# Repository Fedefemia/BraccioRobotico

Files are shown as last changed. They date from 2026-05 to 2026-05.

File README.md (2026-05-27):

# Braccio Robotico 3 DOF - Sistema di Controllo Distribuito MQTT

## Autori: Femia Federico, Storato Nicola
Classe: 5cii
Anno Scolastico: 2025/2026
Panoramica dell'Architettura

Il progetto consiste nell'implementazione hardware e firmware di un braccio robotico a 3 gradi di libertà (DOF). L'architettura prevede un sistema di attuazione e controllo remoto basato sul protocollo di messaggistica asincrona MQTT. Le direttive di posizionamento possono essere iniettate nel sistema tramite interfacce client eterogenee: un'applicazione nativa Android, script operanti su Raspberry Pi, o un'interfaccia client-side eseguita su web browser.
### Specifiche Hardware

    Microcontrollore: ESP32-S3, equipaggiato con antenna esterna per l'ottimizzazione del guadagno RF in ambiente Wi-Fi.

    Attuatori: 4x Servomotori micro MG90S.

    Chassis: Componenti strutturali realizzati in manifattura additiva (stampa 3D) mediante l'estrusione di polimero PLA.

    Topologia di Alimentazione: Rete a doppio rail progettata per mitigare l'interferenza elettromagnetica e le cadute di tensione causate dai transienti di assorbimento induttivo dei motori:

        Rail 1: Alimentazione del modulo logico (ESP32-S3) e di 2 servomotori.

        Rail 2: Alimentazione di potenza dedicata ai restanti 2 servomotori.

### Infrastruttura di Rete e Comunicazione

    Message Broker: Istanza di Eclipse Mosquitto in esecuzione su host Ubuntu.

    Tunneling WAN: Esposizione del servizio MQTT su rete pubblica tramite reverse proxy TCP implementato con ngrok.

    Topic di Sottoscrizione: robot/servos/cmd

    Formato Payload: Parsing di stringhe con delimitatore (CSV) nel formato [ID_SERVO],[ANGOLO_TARGET].

### Architettura del Firmware

Il layer software è sviluppato in C++ tramite il framework Arduino su ambiente PlatformIO.

    Generazione del Segnale di Controllo: Modulazione PWM gestita a livello hardware tramite la periferica nativa LEDC del SoC ESP32. Il segnale opera con una frequenza di 50Hz e una risoluzione a 14-bit, massimizzando la granularità del duty cycle calcolato in virgola mobile.

    Motore Cinematico Non Bloccante: Il firmware esegue una routine di interpolazione asincrona basata sul differenziale temporale (deltaT). Il sistema calcola dinamicamente i micro-step necessari per eseguire transizioni fluide sui motori designati come "lenti", gestendo contemporaneamente il bypass cinematico per gli attuatori che richiedono l'erogazione della massima coppia di spunto in tempo reale.

Dipendenze e Ambiente di Build (platformio.ini)
Ini, TOML

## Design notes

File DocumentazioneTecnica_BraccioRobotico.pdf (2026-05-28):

Sistema di Controllo per Braccio Robotico IoT — Documentazione Tecnica

Pagina 1 di 23

### DOCUMENTAZIONE TECNICA

# Sistema di Controllo per Braccio Robotico IoT

## Progetto IoT con Architettura MQTT

Hardware | ESP32-S3 DevKitC-1
Attuatori | 4x Servo Motor (Spalla, Gomito, Polso, Claw)
Protocollo | MQTT 3.1.1 + WebSocket/TLS
App Mobile | Android (Kotlin + Jetpack Compose)
Simulazione 3D | Three.js / WebGL in WebView
Broker | Eclipse Mosquitto (Docker + Ngrok
Manifattura | FreeCAD + Stampa 3D PLA

2025

Pagina 2 di 23

## Indice dei Contenuti

Pagina 3 di 23

Pagina 4 di 23

## 1. Introduzione e Obiettivi del Progetto

### 1.1 Panoramica Generale

Il presente documento descrive in dettaglio l'architettura, l'implementazione e le soluzioni tecniche adottate nello sviluppo di un sistema di controllo remoto per braccio robotico basato su protocollo MQTT. Il progetto integra componenti hardware, firmware embedded, comunicazione di rete, applicazione mobile nativa e interfaccia web in un'unica piattaforma coerente.

Il sistema consente il controllo in tempo reale di un braccio robotico a 4 gradi di libertà tramite un'applicazione Android con simulazione cinematica 3D, nonché attraverso un'interfaccia web accessibile da browser, il tutto mediato da un broker MQTT ospitato su infrastruttura cloud containerizzata.

### 1.2 Obiettivi Tecnici

- Realizzare un sistema di controllo real-time con latenza minima per 4 servo-motori indipendenti
- Implementare un motore cinematico interpolato per movimenti fluidi e controllati
- Sviluppare un'applicazione Android nativa con rendering 3D del modello cinematico
- Deployare un broker MQTT accessibile da internet tramite tunnel sicuri
- Progettare e stampare in 3D i componenti meccanici del braccio robotico
- Integrare un'interfaccia web di telemetria e controllo manuale

### 1.3 Stack Tecnologico

Livello | Tecnologia | Utilizzo
Hardware | ESP32-S3 DevKitC-1 | Microcontrollore principale, WiFi, LEDC PWM
Firmware | Arduino / PlatformIO | Motore cinematico, MQTT client, controllo servo
Comunicazione | MQTT 3.1.1 (PubSubClient) | Trasporto comandi robot/servos/cmd
Broker | Eclipse Mosquitto + Docker | Gestione messaggi, autenticazione PBKDF2
Tunnel | Ngrok (TCP + HTTPS/WSS) | Esposizione internet sicura dual-listener
App Android | Kotlin + Jetpack Compose | UI nativa, gestione stato, JNI bridge
Rendering 3D | Three.js / WebGL | Simulazione cinematica forward kinematics
Web UI | HTML/JS + Paho MQTT | Interfaccia di controllo e telemetria
CAD/Manifattura | FreeCAD + Stampa 3D PLA | Progettazione e produzione componenti

Pagina 5 di 23

## 2. Architettura del Sistema

### 2.1 Visione d'Insieme

Il sistema adotta un'architettura distribuita a tre livelli principali: il livello di presentazione (App Android e Web UI), il livello di trasporto e orchestrazione (Broker MQTT su infrastruttura Docker/Ngrok) e il livello di attuazione (Firmware ESP32-S3 con controllo servo).

### 2.2 Topologia di Rete

La topologia di rete implementa un pattern publish/subscribe tramite MQTT. I client publisher (App Android, Web UI) inviano comandi al topic robot/servos/cmd sul broker Mosquitto. L'ESP32-S3, registrato come subscriber sullo stesso topic, riceve i comandi e li esegue in tempo reale.

TOPIC MQTT robot/servos/cmd → Formato payload: "<indice_servo>,<angolo>" (es. "1,90")

### 2.3 Flusso Dati End-to-End

1. L'operatore interagisce con l'App Android o la Web UI (jogging continuo o simulazione 3D)
2. Il client MQTT pubblica un messaggio sul topic robot/servos/cmd tramite il broker
3. Il broker Mosquitto autentica il client e instrada il messaggio
4. Il messaggio raggiunge l'ESP32-S3 tramite tunnel Ngrok (TCP raw, porta 25629)
5. Il firmware parsa il payload, aggiorna lo stato target del servo specificato
6. La routine di interpolazione asincrona nel loop() esegue il movimento fluido
7. Il LEDC genera il segnale PWM calibrato sul pin GPIO corrispondente

### 2.4 Protocollo di Comando

Il protocollo di comando è volutamente semplice e a bassa latenza. Il payload è una stringa ASCII composta da due campi separati da virgola:

Formato: "<servo_index>,<angolo_gradi>"
Esempio servo 0 -> 45°: "0,45"
Esempio servo 2 -> 135°: "2,135"
Il firmware esegue validazione sul range dell'indice (0-3) e dell'angolo (0-270°), rigettando i comandi fuori bounds con log su seriale.

### 2.5 Considerazioni sulla Latenza

Pagina 6 di 23

Segmento | Latenza Stimata
App Android → Broker (WiFi locale) | < 10 ms
Web UI → Broker (WebSocket/TLS) | < 50 ms
Broker → ESP32 (Ngrok TCP tunnel) | 20-80 ms (dipendente da rete)
ESP32: parsing + aggiornamento target | < 1 ms
Latenza totale end-to-end (tipica) | 50-150 ms

Pagina 7 di 23

## 3. Hardware: ESP32-S3 e Attuatori

### 3.1 Microcontrollore ESP32-S3 DevKitC-1

L'ESP32-S3 è un System-on-Chip Xtensa LX7 dual-core prodotto da Espressif Systems. La variante DevKitC-1 è stata scelta per la disponibilità di GPIO sufficienti, il modulo WiFi 802.11 b/g/n integrato, e le periferiche hardware necessarie per il controllo PWM multi-canale.

Caratteristica | Valore
CPU | Xtensa LX7 dual-core @ 240 MHz
RAM | 512 KB SRAM + 8 MB PSRAM (ext.)
Flash | 8 MB
WiFi | 802.11 b/g/n 2.4 GHz
Bluetooth | BLE 5.0
GPIO | 36 pin programmabili
LEDC (PWM) | 8 canali timer, risoluzione fino a 14-bit
Tensione operativa | 3.3V (tollerante 5V su alcuni pin)
Alimentazione | USB-C 5V via DevKit

### 3.2 Mappatura Pin GPIO e Canali LEDC

La periferica LEDC (LED Control) dell'ESP32-S3 è utilizzata per generare i segnali PWM a 50Hz necessari per il controllo dei servo-motori. Ogni servo è assegnato a un canale LEDC indipendente per evitare interferenze temporali.

Servo | GPIO Pin | Canale LEDC / Funzione
Servo 0 | GPIO 4 | LEDC CH0 – Spalla (base rotazione)
Servo 1 | GPIO 5 | LEDC CH1 – Gomito (flessione)
Servo 2 | GPIO 47 | LEDC CH2 – Polso (flessione)
Servo 3 | GPIO 48 | LEDC CH3 – Claw (presa)

### 3.3 Parametri PWM e Calibrazione

Il controllo servo avviene tramite modulazione PWM a 50 Hz (periodo 20ms) in accordo con lo standard RC. La larghezza dell'impulso determina la posizione angolare del servo nell'intervallo 0°-270°.

Pagina 8 di 23

Parametro | Valore
Frequenza PWM | 50 Hz (periodo 20.000 µs)
Risoluzione duty cycle | 14-bit (16.384 step)
Impulso minimo (0°) | 500 µs
Impulso massimo (270°) | 2500 µs
Range angolare | 0° – 270°
Formula duty cycle | (pulse_us * 16384) / 20000

// Calcolo duty cycle per un dato angolo (0-270°)
float pulse_us = 500 + (gradi / 270.0) * (2500 - 500); uint32_t duty = (uint32_t)((pulse_us * 16384.0) / 20000.0);

### 3.4 Servo-Motori e Caratteristiche Meccaniche

Il progetto utilizza 4 servo-motori di tipo standard RC. La spalla (Servo 0) è soggetta al carico maggiore essendo all'articolazione base, pertanto è configurata in modalità bypass cinematico (movimento istantaneo) per massimizzare la coppia di spunto. Gli altri tre servo (gomito, polso, claw) beneficiano dell'interpolazione fluida.

Servo | Profilo Cinematico
Servo 0 – Spalla (GPIO 4) | Istantaneo (SPEED = 0.0°/s) – Bypass per carico pesante
Servo 1 – Gomito (GPIO 5) | 60°/s – 270° in 4.5 secondi
Servo 2 – Polso (GPIO 47) | 60°/s – 270° in 4.5 secondi
Servo 3 – Claw (GPIO 48) | 60°/s – 270° in 4.5 secondi

Pagina 9 di 23

## 4. Firmware ESP32-S3 (PlatformIO / Arduino)

### 4.1 Ambiente di Sviluppo: PlatformIO

Il firmware è sviluppato con il framework Arduino su PlatformIO IDE, scelto per la gestione avanzata delle dipendenze, la configurazione esplicita dell'ambiente target e l'integrazione con sistemi di build moderni.

platformio.ini

[env:esp32-s3-devkitc-1] | platform = espressif32@~6.5.0 | board =
esp32-s3-devkitc-1 | framework = arduino | lib_deps =
knolleary/PubSubClient@^2.8

### 4.2 Architettura del Firmware

Il firmware è strutturato attorno a tre responsabilità principali: gestione della connettività di rete (WiFi + MQTT), ricezione e validazione dei comandi, e routine di interpolazione cinematica asincrona non bloccante.

### 4.2.1 Struttura Dati ServoState

Lo stato di ogni servo è mantenuto in una struttura dati dedicata che separa la posizione corrente dalla posizione target, abilitando l'interpolazione fluida indipendente per ciascun attuatore.

struct ServoState {
float currentAngle; | // Angolo corrente (aggiornato ad ogni step)
float targetAngle; | // Angolo di destinazione (iniettato da MQTT)
uint32_t lastUpdate; | // Timestamp ultimo aggiornamento (millis())
};
ServoState servoData[NUM_SERVOS]; // Array di 4 istanze

### 4.2.2 Callback MQTT e Validazione

La callback mqtt_callback() è invocata dalla libreria PubSubClient ogni volta che un messaggio arriva sul topic sottoscritto. La validazione comprende il controllo del formato del payload, il range dell'indice servo (0-3) e il clamping dell'angolo nell'intervallo fisico (0-270°).

void mqtt_callback(char* topic, byte* payload, unsigned int length) {
// Ricostruzione stringa dal buffer byte[]
String msg = "";
for (unsigned int i = 0; i < length; i++) msg += (char)payload[i];

int delimiter = msg.indexOf(',');
if (delimiter != -1) {
int idx = msg.substring(0, delimiter).toInt(); int angle = msg.substring(delimiter + 1).toInt(); angle = constrain(angle, 0, 270); // Clamping fisico

Pagina 10 di 23

if (idx >= 0 && idx < NUM_SERVOS) servoData[idx].targetAngle = (float)angle; }
}

### 4.2.3 Routine di Interpolazione Asincrona

Il nucleo del motore cinematico risiede nel loop principale e utilizza il pattern delta-time per calcolare incrementi di posizione indipendenti dalla frequenza di esecuzione del loop. Questo garantisce velocità angolare costante indipendentemente dal carico computazionale.

void loop() {
client.loop(); // Processamento stream MQTT (non bloccante) uint32_t now = millis();

for (uint8_t i = 0; i < NUM_SERVOS; i++) {
float deltaT = (now - servoData[i].lastUpdate) / 1000.0f; servoData[i].lastUpdate = now;

if (abs(servoData[i].targetAngle - servoData[i].currentAngle) > 0.1f) {
if (SPEED_DEG_PER_SEC[i] == 0.0f) { | // Bypass cinematico
servoData[i].currentAngle = servoData[i].targetAngle;
} else { | // Interpolazione
fluida
float step = SPEED_DEG_PER_SEC[i] * deltaT;
// ... avanzamento con clamping al target
}
ledcWrite(LEDC_CHANNELS[i], calcolaDuty(servoData[i].currentAngle)); }
}
}

### 4.3 Gestione della Connettività

### 4.3.1 WiFi

La connessione WiFi è gestita tramite la libreria WiFi.h nativa dell'SDK Espressif. Il firmware effettua il binding sulla rete con polling bloccante solo in fase di setup(). In caso di disconnessione durante l'operatività, la funzione reconnect() gestisce il re-handshake MQTT con retry a 3 secondi.

### 4.3.2 Client MQTT (PubSubClient)

La libreria PubSubClient di Nick O'Leary fornisce un client MQTT 3.1.1 asincrono integrato nel loop Arduino. Il client si connette al broker tramite TCP raw (tunnel Ngrok) con autenticazione username/password. L'identificatore client è generato casualmente ad ogni connessione per evitare conflitti di sessione.

Pagina 11 di 23

String clientId = "ESP32S3-KINEMATICS-" + String(random(0xffff), HEX); client.connect(clientId.c_str(), mqtt_user, mqtt_pass); client.subscribe(topic_cmd); // "robot/servos/cmd"

Pagina 12 di 23

## 5. Infrastruttura Broker MQTT

### 5.1 Eclipse Mosquitto su Docker

Il broker MQTT è deployato come container Docker basato sull'immagine ufficiale eclipse-mosquitto. La scelta di Docker garantisce portabilità, isolamento dell'ambiente e semplicità di gestione del processo con restart policy automatica.

Componente | Configurazione
Immagine Docker | eclipse-mosquitto (latest)
Nome container | mqtt-broker
Restart policy | unless-stopped (demone persistente)
Rete Docker interna | ngrok-net (bridge isolata)
Porte esposte all'host | Nessuna (traffico solo via Ngrok)
Configurazione | /opt/mqtt-ngrok/config/mosquitto.conf
File credenziali | /opt/mqtt-ngrok/config/passwd (PBKDF2)
Dati persistenti | /opt/mqtt-ngrok/data
Log directory | /opt/mqtt-ngrok/log

### 5.2 Configurazione Dual-Listener

Mosquitto è configurato con due listener indipendenti per supportare contemporaneamente client IoT (ESP32) e client web (browser). Questa configurazione permette di utilizzare il protocollo nativo MQTT su TCP per i microcontrollori e MQTT over WebSocket per i browser, che non possono aprire socket TCP raw.

Listener | Dettagli
Listener 1 – Raw TCP | Porta 1883, bind 0.0.0.0, protocollo MQTT standard
Listener 2 – WebSocket | Porta 9001, bind 0.0.0.0, protocollo MQTT over WS
Autenticazione | Obbligatoria su entrambi (allow_anonymous false)
Hash password | PBKDF2 (mosquitto_passwd)

### 5.3 Tunnel Ngrok: Architettura Dual-Endpoint

Il container ngrok-agent è configurato tramite ngrok.yml con due tunnel simultanei per esporre entrambi i listener Mosquitto su internet. Il tunnel TCP espone la porta 1883 con un FQDN e porta dinamici allocati nel cloud Ngrok, mentre il tunnel HTTP/HTTPS espone la porta 9001 con TLS automatico.

Pagina 13 di 23

Tunnel TCP
(ESP32)

Endpoint: 6.tcp.eu.ngrok.io:25629 → mqtt-broker:1883 (Raw MQTT per microcontrollori)

Tunnel
HTTPS/WSS
(Browser)

Endpoint: *.ngrok-free.dev:443 → mqtt-broker:9001 (MQTT over WebSocket + TLS)

### 5.4 Script di Status Globale

Lo script mqtt-status (installato in /usr/local/bin/) interroga le API REST interne dell'agente Ngrok per estrarre dinamicamente gli FQDN e le porte allocate nel cloud, restituendo in stdout i parametri di connessione aggiornati per entrambi i tipi di client.

### 5.5 Sicurezza e Autenticazione

Il sistema implementa un modello di sicurezza a più livelli: autenticazione MQTT obbligatoria con credenziali hashate PBKDF2, traffico web cifrato TLS 1.3 tramite Ngrok, isolamento L4 con nessuna porta esposta direttamente sull'host, e rete Docker interna bridge con accesso controllato solo tra i container autorizzati.

Pagina 14 di 23

## 6. Applicazione Android (Kotlin + Jetpack Compose)

### 6.1 Architettura Ibrida Nativa/Web

L'applicazione Android adotta un'architettura ibrida innovativa: l'interfaccia utente e la logica di controllo sono implementate in Kotlin con Jetpack Compose (framework UI dichiarativo nativo), mentre il motore di rendering 3D è una WebView che ospita un'applicazione Three.js/WebGL. La comunicazione bidirezionale tra layer nativo e web avviene tramite JNI/JavascriptInterface.

Layer | Responsabilità
Kotlin / Compose (Nativo) | State management, UI controls, MQTT client, JNI bridge
WebView / Three.js (Web) | Rendering 3D STL, forward kinematics, debug overlay
JNI JavascriptInterface | Bridge bidirezionale per aggiornamenti cinematici

### 6.2 Client MQTT Asincrono

L'app implementa un client MQTT asincrono che pubblica comandi di controllo sul topic robot/servos/cmd. Il client è inizializzato con le credenziali del broker e gestisce riconnessioni automatiche in caso di perdita del link di rete.

### 6.3 Simulazione Cinematica 3D (Three.js in WebView)

### 6.3.1 Albero Cinematico

La simulazione implementa un modello di Forward Kinematics (FK) basato su un albero gerarchico a 4 nodi. Ogni nodo figlio eredita le trasformazioni del nodo padre, simulando il comportamento reale del braccio articolato.

Indice Nodo | Componente | Dettagli
0 | Base Statica (BaseArm-Body.stl) | Parent: -1 – Ancora al mondo, non ruota
1 | Spalla (Arm2_final.stl) | Parent: 0, Asse Y – Attuatore 0
2 | Gomito (Arm3_final.stl) | Parent: 1, Asse X – Attuatore 1
3 | Polso / End-Effector (Arm4.stl) | Parent: 2, Asse X – Attuatore 2

### 6.3.2 Caricamento STL e WebViewAssetLoader

I modelli STL sono serviti alla WebView tramite WebViewAssetLoader, che intercetta le richieste HTTP verso il dominio virtuale https://appassets.androidplatform.net e le risolve sugli asset bundlati nell'APK. Questo aggira le restrizioni di sicurezza di Chromium API 30+ che bloccano le richieste XHR verso percorsi file://.

Pagina 15 di 23

// Configurazione WebViewAssetLoader
val assetLoader = WebViewAssetLoader.Builder() .addPathHandler("/assets/", AssetsPathHandler(context)) .build()
// STLLoader carica da:
https://appassets.androidplatform.net/assets/model.stl

### 6.4 Criticità Architetturali Risolte

### 6.4.1 Vertex Normals Mancanti (Black Shading)

I file CAD esportati in STL non includono dati di normali per vertice, causando un rendering completamente nero con MeshPhongMaterial. La soluzione implementata esegue il calcolo automatico delle normali a runtime su Three.js prima del calcolo dei bounding box.

// Risoluzione black shading su modelli STL CAD geometry.computeVertexNormals(); // Calcolo normali a runtime const material = new THREE.MeshPhongMaterial({ color: 0x888888 });

### 6.4.2 Disallineamento Pivot-Mesh (CAD Offset)

I modelli CAD non hanno il fulcro di rotazione centrato sull'origine geometrica, causando rotazioni errate. La soluzione disaccoppia il pivot di rotazione (jointPos) dall'offset della geometria rispetto al fulcro (meshOffset, meshRotation), permettendo compensazioni vettoriali precise per ogni link.

### 6.4.3 Mappatura Dominio JNI (0-indexed vs 1-indexed)

Gli attuatori fisici nell'array Android sono 0-indexed (0-3), mentre i nodi figlio in Three.js sono 1-indexed (il nodo 0 è la base statica). Un offset logico +1 nella mappatura JNI risolve l'ambiguità senza modificare né il firmware né il rendering.

### 6.5 Strato di Debug e Calibrazione

L'app implementa uno strato di "Calibrazione Costruttiva" nello state management di Compose che esporta a runtime verso JavaScript i seguenti parametri manipolabili in tempo reale:

- Posizione del Pivot (X, Y, Z) per ogni link
- Offset Traslazionale della Mesh (X, Y, Z) rispetto al pivot
- Rotazione Assoluta della Mesh (Pitch, Yaw, Roll) per correzione CAD
- OrbitControls attivi sulla canvas 3D per ispezione del frustum da qualsiasi angolo

Pagina 16 di 23

## 7. Interfaccia Web di Controllo

### 7.1 Architettura e Stack

L'interfaccia web è una Single Page Application (SPA) vanilla HTML/CSS/JS che non richiede build tools o framework. Si connette al broker MQTT tramite la libreria Paho MQTT su WebSocket con TLS, sfruttando il secondo listener Mosquitto su porta 9001 esposto via tunnel Ngrok HTTPS.

Componente | Implementazione
MQTT Client | Eclipse Paho JavaScript (mqttws31.min.js da CDN)
Trasporto | WebSocket su TLS (WSS) – Ngrok HTTPS endpoint
UI Pattern | Jogging continuo con hold-to-move (mousedown/touchstart)
Stile | Dark theme monocromatico, font monospace

### 7.2 Controllo Vettoriale Continuo (Jogging)

L'interfaccia implementa un pattern di controllo jogging: invece di inviare un angolo assoluto, l'operatore tiene premuto il pulsante + o - per muovere il servo nella direzione desiderata. Il sistema invia aggiornamenti ogni 100ms finché il pulsante è premuto.

// Pattern startMove/stopMove
function startMove(idx, step, event) {
if (event) event.preventDefault(); // Evita doppio trigger touch angles[idx] = Math.max(0, Math.min(270, angles[idx] + step)); sendUpdate(idx); // Invio immediato al click
moveInterval = setInterval(() => {
angles[idx] += step;
if (angles[idx] >= 270 || angles[idx] <= 0) clearInterval(moveInterval); sendUpdate(idx); // Aggiornamenti continui ogni 100ms }, 100);
}

### 7.3 Compatibilità Mobile e Touch

L'interfaccia è ottimizzata per l'uso su dispositivi touch tramite event listener dedicati: ontouchstart e ontouchend gestiscono gli eventi touch, con event.preventDefault() per sopprimere il comportamento di doppio-click nativo dei browser mobile. La proprietà CSS touch-action: manipulation disabilita lo zoom su doppio tap.

### 7.4 Gestione dello Stato degli Angoli

Pagina 17 di 23

Lo stato degli angoli è mantenuto in memoria JavaScript in un array di 4 elementi, inizializzato a 135° (posizione centrale del range 0-270°). Ogni aggiornamento locale dell'array viene immediatamente riflesso sull'etichetta visuale e inviato via MQTT al broker.

let angles = [135, 135, 135, 135]; // Posizione iniziale centrata
function sendUpdate(idx) { document.getElementById(`val_${idx}`).innerText = angles[idx] + "°"; const message = new Paho.MQTT.Message(`${idx},${angles[idx]}`); message.destinationName = topic_cmd;
client.send(message);
}

Pagina 18 di 23

## 8. Progettazione e Manifattura Meccanica

### 8.1 Processo di Design CAD (FreeCAD)

I componenti meccanici del braccio robotico sono stati progettati interamente in FreeCAD, software CAD open-source parametrico. Il design ha richiesto 7 ore complessive di lavoro, suddivise tra la modellazione dei singoli link, il dimensionamento delle sedi per i servo-motori e l'ottimizzazione delle geometrie per la stampa 3D.

### 8.2 Componenti Progettati

File STL | Componente
BaseArm-Body.stl | Base statica – Struttura di ancoraggio al piano di lavoro
Arm2_final.stl | Link 1 / Spalla – Articolazione di rotazione sull'asse Y
Arm3_final.stl | Link 2 / Gomito – Articolazione di flessione sull'asse X
Arm4.stl | Link 3 / Polso – End-Effector, flessione asse X

### 8.3 Stampa 3D

I componenti sono stati prodotti tramite stampa FDM (Fused Deposition Modeling) utilizzando filamento PLA (Acido Polilattico). Il PLA è stato scelto per la facilità di stampa, la rigidità meccanica sufficiente per carichi statici moderati, e la disponibilità.

Parametro | Valore
Materiale | PLA (Polylactic Acid)
Processo | FDM (Fused Deposition Modeling)
Tempo totale di design CAD | ~7 ore
Tempo totale di stampa | ~35 ore
Configurazione pinza | Deprecata (rimossa dall'albero cinematico)

### 8.4 Note sulla Configurazione Pinza

La configurazione a pinza biforcata originariamente prevista per il Servo 3 (claw) è stata deprecata e rimossa dall'albero cinematico durante lo sviluppo. La decisione è stata presa per semplificare il modello di simulazione 3D e la logica di controllo. Il Servo 3 rimane fisicamente presente e controllabile via MQTT, ma il corrispondente link non è rappresentato nella simulazione Three.js.

Pagina 19 di 23

## 9. Test e Validazione

### 9.1 Test del Firmware

### 9.1.1 Test Connettività MQTT

La connettività MQTT è stata verificata tramite il monitor seriale di PlatformIO a 115200 baud. Il log mostra chiaramente le fasi di handshake WiFi, il binding TCP con il broker tramite Ngrok, e la ricezione dei comandi.

[WIFI] Binding in corso su MERCUSYS_RE_8F7D .... [WIFI] Link UP. IP: 192.168.1.XXX
[MQTT] Handshake TCP in corso... OK
[CMD] Nuovo target iniettato: Servo 1 -> 90 gradi

### 9.1.2 Test Interpolazione Cinematica

Il comportamento di interpolazione è stato validato osservando il movimento fisico dei servo durante l'invio di comandi incrementali. Il profilo a 60°/s garantisce movimenti fluidi e prevedibili, con clamping corretto al raggiungimento del target.

### 9.2 Test dell'Interfaccia Web

L'interfaccia web è stata testata su browser desktop (Chrome, Firefox) e mobile (Chrome Android). Il pattern jogging con hold-to-move funziona correttamente su entrambi i paradigmi di input, con soppressione del doppio trigger su touch.

### 9.3 Test della Simulazione 3D

La correttezza della simulazione forward kinematics è stata verificata visivamente utilizzando i parametri di debug esportati dalla app: i pivot sono stati calibrati in modo che la rotazione simulata di ogni link corrisponda al comportamento fisico del braccio. Lo strato di Calibrazione Costruttiva ha permesso di correggere gli offset CAD senza ricompilare il codice.

### 9.4 Metriche di Prestazione

Metrica | Risultato
Latenza MQTT (LAN) | < 15 ms (app Android → ESP32)
Latenza MQTT (WAN/Web) | 40-100 ms (browser → ESP32 via Ngrok)
Frequenza loop ESP32 | ~1 kHz (non bloccante con client.loop())
Smoothness interpolazione | Fluida a 60°/s, nessun jitter rilevato

Pagina 20 di 23

Metrica | Risultato
Stabilità broker 24h | Uptime 100% con restart policy Docker

Pagina 21 di 23

## 10. Sicurezza del Sistema

### 10.1 Modello di Minaccia

Il sistema espone endpoint MQTT su internet tramite Ngrok. Il modello di sicurezza adottato affronta le principali superfici di attacco: accesso non autorizzato al broker, intercettazione del traffico, e iniezione di comandi malevoli.

### 10.2 Misure Implementate

Misura | Implementazione
Autenticazione MQTT | Username/password obbligatori, hash PBKDF2 (mosquitto_passwd)
Cifratura traffico web | TLS 1.3 su endpoint HTTPS/WSS Ngrok
Isolamento rete | Nessuna porta esposta direttamente sull'host Docker
Segmentazione container | Rete bridge ngrok-net isolata tra mqtt-broker e ngrok-agent
Validazione input ESP32 | Clamping indice (0-3) e angolo (0-270°) nel firmware

### 10.3 Limitazioni e Raccomandazioni Future

- Le credenziali MQTT sono hardcoded nel firmware ESP32: in produzione, utilizzare NVS (Non-Volatile Storage) o un provisioning system
- Il tunnel Ngrok gratuito ha limiti di connessioni simultanee e non garantisce SLA: in produzione, utilizzare un server VPS con IP fisso
- Aggiungere autenticazione TLS client-side sul broker per i client IoT
- Implementare un sistema di autorizzazione per topic MQTT (ACL) per limitare i permessi per client

Pagina 22 di 23

## 11. Conclusioni e Sviluppi Futuri

### 11.1 Risultati Raggiunti

Il progetto ha raggiunto tutti gli obiettivi prefissati: il braccio robotico è controllabile in tempo reale da qualsiasi dispositivo connesso a internet tramite l'applicazione Android o l'interfaccia web. L'interpolazione cinematica garantisce movimenti fluidi, e la simulazione 3D fornisce un feedback visivo immediato e accurato dello stato del braccio.

Le criticità architetturali affrontate durante lo sviluppo – dalla gestione dei CORS in WebView alle normali mancanti nei file CAD, dal disallineamento pivot-mesh alla mappatura degli indici JNI – hanno arricchito il know-how tecnico e portato a soluzioni robuste e riutilizzabili.

### 11.2 Sviluppi Futuri

### 11.2.1 Inverse Kinematics (IK)

Il passo naturale successivo è l'implementazione di un motore di Inverse Kinematics: l'operatore specificherebbe la posizione cartesiana desiderata dell'end-effector e il sistema calcolerebbe automaticamente gli angoli articolari necessari. Algoritmi come FABRIK o Jacobian pseudo-inverse sono adatti per questo tipo di configurazione planare.

### 11.2.2 Controllo a Traiettoria

Implementare la pianificazione di traiettorie multi-punto con profili di velocità trapezoidali (accelerazione/decelerazione graduale), migliorando la fluidità e riducendo lo stress meccanico durante movimenti complessi.

### 11.2.3 Feedback di Posizione

Aggiungere encoders o sensori di posizione angolare (potenziometri o encoder magnetici AS5600) per implementare un loop di controllo in retroazione, superando il controllo open-loop attuale.

### 11.2.4 Claw Funzionale

Ripristinare e aggiornare la configurazione della pinza (Servo 3), progettando un nuovo meccanismo di presa e reintegrando il link nell'albero cinematico della simulazione 3D.

### 11.2.5 Infrastruttura Produzione

Migrare l'infrastruttura broker da Ngrok a un VPS dedicato con IP fisso, certificato TLS Let's Encrypt e broker MQTT con QoS 1/2 per garantire la consegna affidabile dei comandi.

Pagina 23 di 23

### 11.3 Conclusioni

Il progetto dimostra come sia possibile realizzare un sistema IoT completo e funzionale integrando tecnologie eterogenee: hardware embedded, protocolli di messaging distribuito, sviluppo mobile nativo, rendering 3D web-based e containerizzazione cloud. La separazione netta delle responsabilità tra i layer garantisce manutenibilità e scalabilità del sistema verso evoluzioni future.

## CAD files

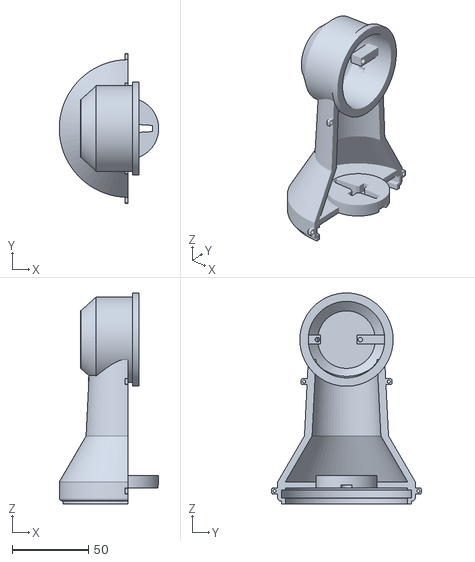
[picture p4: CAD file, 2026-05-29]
Android/app/src/main/assets/Arm2_final.stl
65.0 x 98.0 x 138.0

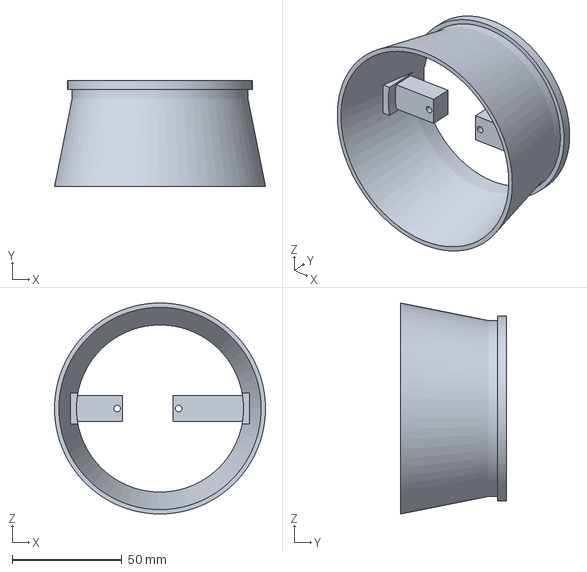
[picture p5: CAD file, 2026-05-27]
Models/3mf/BaseArm-Body.3mf
96.0 x 48.0 x 96.0 mm

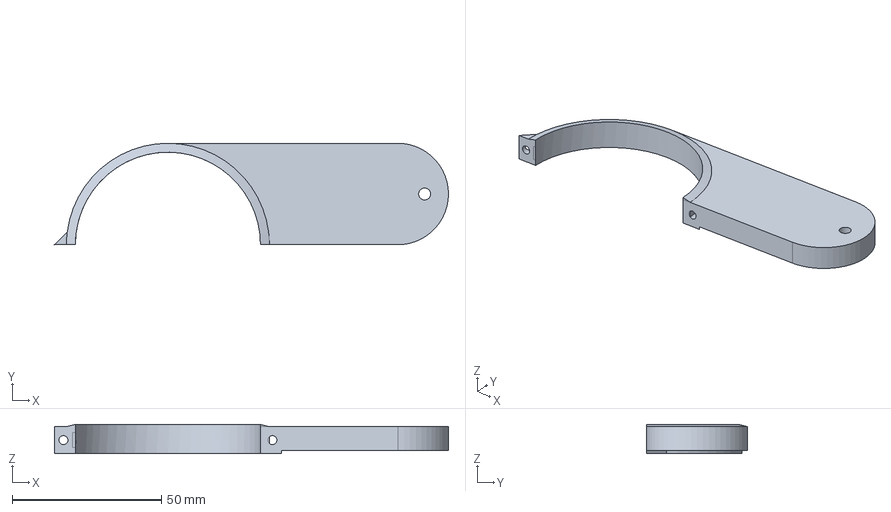
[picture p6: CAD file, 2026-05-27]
Models/FCStd/Arm3_complementary.FCStd
132.0 x 34.0 x 9.75 mm

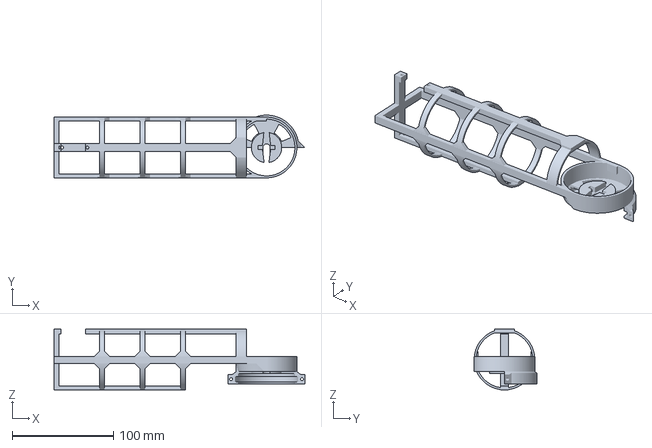
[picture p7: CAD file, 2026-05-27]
Models/3mf/Arm3_final.3mf
248.0 x 62.0 x 60.0 mm

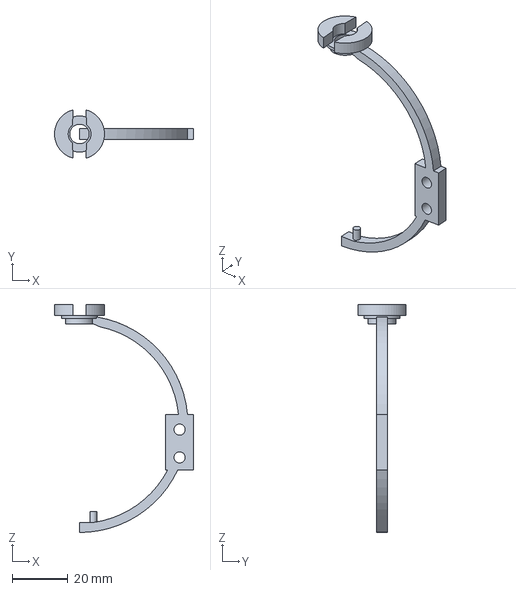
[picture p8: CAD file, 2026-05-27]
Models/FCStd/Arm4_final.FCStd
50.0 x 17.4 x 82.0 mm

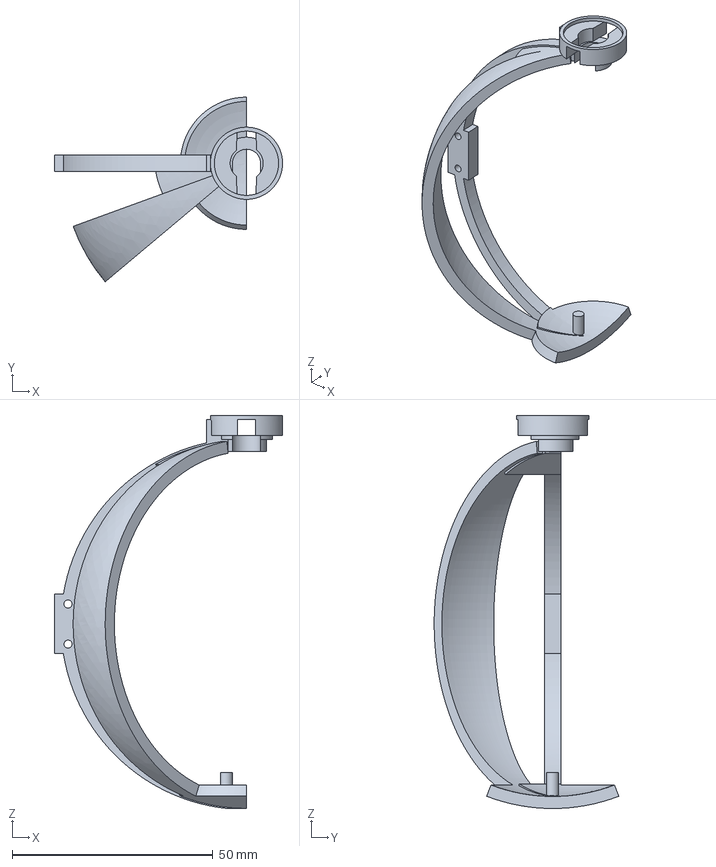
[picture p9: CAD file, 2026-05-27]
Models/3mf/Arm4.3mf
56.9 x 46.1 x 98.0 mm

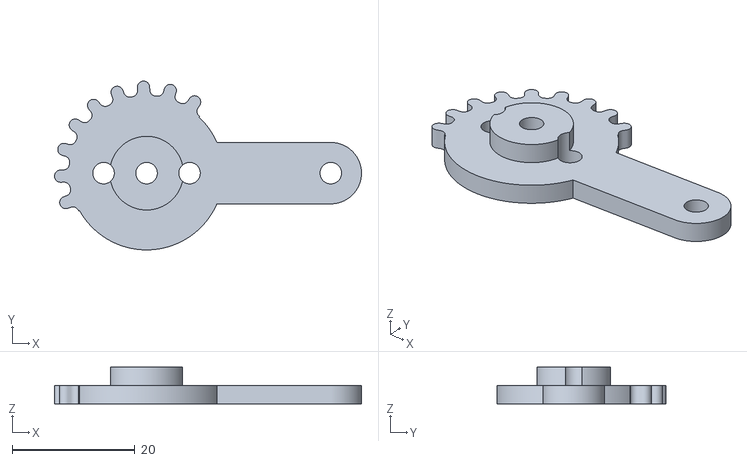
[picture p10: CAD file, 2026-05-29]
Android/app/src/main/assets/claw2.stl
50.0 x 27.5 x 6.00

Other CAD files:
Android/app/src/main/assets/Arm3_complementary-Body.stl
Models/FCStd/BaseArm.FCStd
Android/app/src/main/assets/Arm3_final.stl
Models/3mf/Arm3_complementary-Body.3mf
Android/app/src/main/assets/BaseArm-Body.stl
Android/app/src/main/assets/Arm4.stl
Models/3mf/Arm2_final.3mf

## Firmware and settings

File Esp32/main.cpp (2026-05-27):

#include <Arduino.h>
#include <WiFi.h>
#include <PubSubClient.h>

// Credenziali Rete e MQTT
const char* ssid = "MERCUSYS_RE_8F7D";
const char* password = "12101210";
const char* mqtt_server = "6.tcp.eu.ngrok.io";
const int mqtt_port = 25629;
const char* mqtt_user = "admin";
const char* mqtt_pass = "mqtt_secure_pass";
const char* topic_cmd = "robot/servos/cmd";

WiFiClient espClient;
PubSubClient client(espClient);

// Topologia LEDC Nativa
constexpr uint8_t NUM_SERVOS = 4;
constexpr uint8_t SERVO_PINS[NUM_SERVOS] = {4, 5, 47, 48};
constexpr uint8_t LEDC_CHANNELS[NUM_SERVOS] = {0, 1, 2, 3}; 

// Parametri temporali PWM (50Hz, risoluzione 14-bit)
constexpr uint32_t PWM_FREQ = 50;
constexpr uint8_t PWM_RES = 14; 
constexpr uint16_t SERVO_MIN_PULSE = 500;  
constexpr uint16_t SERVO_MAX_PULSE = 2500; 

// ==========================================
// PROFILI CINEMATICI INDIPENDENTI
// ==========================================
// 0.0 = Movimento istantaneo (Massima coppia di spunto, nessuna interpolazione)
// 60.0 = 270 gradi in 4.5 secondi
constexpr float SPEED_DEG_PER_SEC[NUM_SERVOS] = {
    0.0,   // Servo 0 (GPIO 4)  - Pesante: Bypass cinematico
    60.0,  // Servo 1 (GPIO 5)  - Lento: 4.5s
    60.0,  // Servo 2 (GPIO 47) - Lento: 4.5s
    60.0   // Servo 3 (GPIO 48) - Lento: 4.5s
};

struct ServoState {
    float currentAngle;
    float targetAngle;
    uint32_t lastUpdate;
};

ServoState servoData[NUM_SERVOS];

// Calcolo Duty Cycle operando in virgola mobile
uint32_t calcolaDuty(float gradi) {
    if (gradi > 270.0) gradi = 270.0;
    if (gradi < 0.0) gradi = 0.0;
    
    float pulse_us = SERVO_MIN_PULSE + (gradi / 270.0) * (SERVO_MAX_PULSE - SERVO_MIN_PULSE);
    return (uint32_t)((pulse_us * 16384.0) / 20000.0);
}

void setup_wifi() {
    Serial.printf("\n[WIFI] Binding in corso su %s ", ssid);
    WiFi.begin(ssid, password);
    while (WiFi.status() != WL_CONNECTED) {
        delay(500);
        Serial.print(".");
    }
    Serial.printf("\n[WIFI] Link UP. IP: %s\n", WiFi.localIP().toString().c_str());
}

void mqtt_callback(char* topic, byte* payload, unsigned int length) {
    String msg = "";
    for (unsigned int i = 0; i < length; i++) {
        msg += (char)payload[i];
    }
    
    int delimiter = msg.indexOf(',');
    if (delimiter != -1) {
        int idx = msg.substring(0, delimiter).toInt();
        int angle = msg.substring(delimiter + 1).toInt();

        if (idx >= 0 && idx < NUM_SERVOS) {
            if (angle < 0) angle = 0;
            if (angle > 270) angle = 270;
            
            servoData[idx].targetAngle = (float)angle;
            Serial.printf("[CMD] Nuovo target iniettato: Servo %d -> %d gradi\n", idx, angle);
        } else {
            Serial.println("[ERR] Operazione rigettata: Indice out-of-bounds");
        }
    }
}

void reconnect() {
    while (!client.connected()) {
        Serial.print("[MQTT] Handshake TCP in corso... ");
        String clientId = "ESP32S3-KINEMATICS-" + String(random(0xffff), HEX);
        
        if (client.connect(clientId.c_str(), mqtt_user, mqtt_pass)) {
            Serial.println("OK");
            client.subscribe(topic_cmd);
        } else {
            Serial.printf("DROP. RC=%d. Retry in 3s.\n", client.state());
            delay(3000);
        }
    }
}

void setup() {
    Serial.begin(115200);
    delay(1000);
    Serial.println("\n[SYSTEM] Inizializzazione motore cinematico non bloccante");

    for (uint8_t i = 0; i < NUM_SERVOS; i++) {
        ledcSetup(LEDC_CHANNELS[i], PWM_FREQ, PWM_RES);
        ledcAttachPin(SERVO_PINS[i], LEDC_CHANNELS[i]);
        
        // Inizializzazione struttura dati (Avvio a 90 gradi)
        servoData[i].currentAngle = 90.0;
        servoData[i].targetAngle = 90.0;
        servoData[i].lastUpdate = millis();
        
        // Setup layer fisico al boot
        ledcWrite(LEDC_CHANNELS[i], calcolaDuty(servoData[i].currentAngle));
    }

    setup_wifi();
    client.setServer(mqtt_server, mqtt_port);
    client.setCallback(mqtt_callback);
}

void loop() {
    if (!client.connected()) {
        reconnect();
    }
    client.loop(); // Processamento stream di rete

    // ==========================================
    // ROUTINE DI INTERPOLAZIONE ASINCRONA
    // ==========================================
    uint32_t now = millis();
    
    for (uint8_t i = 0; i < NUM_SERVOS; i++) {
        float deltaT = (now - servoData[i].lastUpdate) / 1000.0;
        servoData[i].lastUpdate = now;

        // Esegue se c'è discrepanza tra posizione corrente e target
        if (abs(servoData[i].targetAngle - servoData[i].currentAngle) > 0.1) {
            
            // Bypass cinematico per carichi pesanti
            if (SPEED_DEG_PER_SEC[i] == 0.0) {
                servoData[i].currentAngle = servoData[i].targetAngle;
                ledcWrite(LEDC_CHANNELS[i], calcolaDuty(servoData[i].currentAngle));
                continue; // Salta il resto del calcolo per questo servo
            }
            
            // Interpolazione fluida per gli altri
            float step = SPEED_DEG_PER_SEC[i] * deltaT;
            
            if (servoData[i].targetAngle > servoData[i].currentAngle) {
                servoData[i].currentAngle += step;
                if (servoData[i].currentAngle > servoData[i].targetAngle) {
                    servoData[i].currentAngle = servoData[i].targetAngle; // Clamping
                }
            } else {
                servoData[i].currentAngle -= step;
                if (servoData[i].currentAngle < servoData[i].targetAngle) {
                    servoData[i].currentAngle = servoData[i].targetAngle; // Clamping
                }
            }
            
            // Scrittura del micro-step
            ledcWrite(LEDC_CHANNELS[i], calcolaDuty(servoData[i].currentAngle));
        }
    }
}
